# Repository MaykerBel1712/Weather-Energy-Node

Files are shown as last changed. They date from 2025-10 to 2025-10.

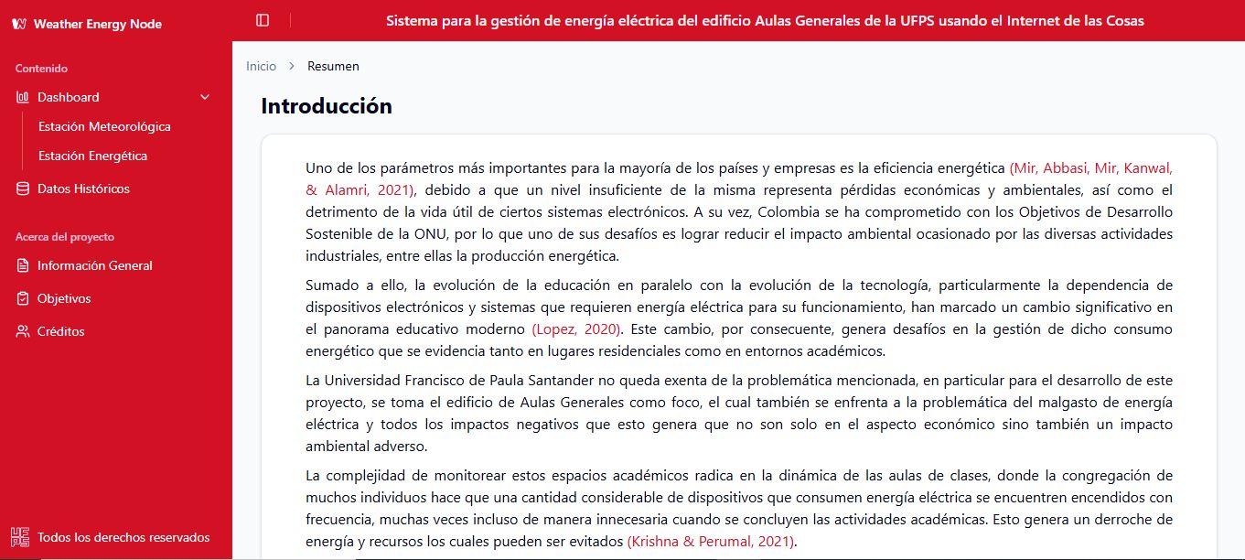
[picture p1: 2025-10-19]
docs/Página/INFO.JPG

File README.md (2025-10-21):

# Proyecto de Tesis — Sistema Integrado de Monitoreo Ambiental, Energético y Domótica UFPS

## 📘 Descripción general

Este proyecto corresponde al desarrollo de una **plataforma integral de monitoreo y control** para el edificio de Aulas Generales de la **Universidad Francisco de Paula Santander (UFPS)**.
Combina módulos de **estación meteorológica**, **monitoreo energético** y **domótica**, integrados a una **plataforma web interactiva** con visualización de datos en tiempo real.

---

## Componentes del sistema

### 1. Estación Meteorológica

* Microcontrolador: **ESP32**
* Sensores: temperatura, humedad, radiación solar, velocidad del viento, material particulado (PM1.0, PM2.5, PM4.0, PM10) e índice VOC.
* Funcionalidad: recolección y envío de datos a **Firebase Realtime Database**.
* Mecanismo de respaldo: almacenamiento temporal en memoria interna cuando no hay conexión a internet.

### 2. Módulo de Monitoreo Energético

* Microcontrolador: **ESP32**
* Sensor: medidor Eastron SDM630MTC (RS485)
* Funcionalidad: medición de variables eléctricas del edificio, envío a Firebase y almacenamiento local en caso de pérdida de conexión.

### 3. Módulos de Domótica

* Módulo **transmisor**: detecta presencia y envía señal.
* Módulo **receptor**: acciona dispositivos eléctricos del salón.
* Tecnología: comunicación inalámbrica entre módulos basados en ESP32.

### 4. Plataforma Web

* Framework: **Next.js**
* Estilo: **Tailwind CSS + shadcn/ui**
* Funcionalidades:

  * Visualización de datos meteorológicos y energéticos en tiempo real.
  * Gráficas interactivas con **Plotly.js**.
  * Panel principal de control (Dashboard).
  * Integración con Firebase Hosting y Database.

---

## Estructura del Repositorio

Cada subcarpeta incluye su propio `README.md` explicando su función y configuración.

```
.gerber/           → Archivos de los circuitos impresos
firmware/          → Códigos de los ESP32
web_app/           → Página web del sistema
docs/              → Documentación técnica, diagramas e imágenes del proceso de desarrollo
```

---

##  Infraestructura general

El sistema opera bajo el siguiente flujo:

1. **Captura de datos** desde sensores (ambientales y eléctricos).
2. **Transmisión** mediante ESP32 hacia Firebase Realtime Database.
3. **Visualización y control** a través de la página web alojada en Firebase Hosting.
4. **Respaldo local** en memoria interna del ESP32 cuando no hay conexión.

---

## Tecnologías principales

* **ESP32** (Programado en PlatformIO / Arduino)
* **Firebase Realtime Database & Hosting**
* **Next.js + Tailwind CSS + shadcn**
* **C++ / JavaScript / HTML / CSS**

---

##  Autores

* Mayker Beltrán
  *Ingeniería Electrónica — Universidad Francisco de Paula Santander (UFPS)*
* Jesús López
  *Ingeniería Electrónica — Universidad Francisco de Paula Santander (UFPS)*
* Sergio Sepúlveda
  *Ingeniería Electrónica — Universidad Francisco de Paula Santander (UFPS)*
* Mario Illera
  *Ingeniería Electrónica — Universidad Francisco de Paula Santander (UFPS)*

---

##  Licencia

Este proyecto se distribuye bajo la licencia **MIT**, permitiendo su uso académico y de investigación.

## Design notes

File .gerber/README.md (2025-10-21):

# Archivos Gerber de las PCB

Este directorio contiene los archivos **Gerber** generados para la fabricación de las diferentes placas de circuito impreso (PCB) del proyecto en la plataforma EasyEDA. Cada carpeta corresponde a un módulo o sistema específico dentro del diseño general.

## 📁 Estructura de carpetas

- **Gerber_ModuloDeteccion_PCB_ModuloDeteccion**  
  Contiene los archivos Gerber del módulo encargado de la detección de eventos o señales en el sistema.

- **Gerber_ModuloSSR_PCB_ModuloSSR**  
  Incluye los archivos Gerber del módulo de control mediante relés de estado sólido (SSR).

- **Gerber_PCB_1_Energia_PCB_PCB_1_Energia**  
  Archivos Gerber correspondientes al módulo de gestión y monitoreo de energía eléctrica.

- **Gerber_PCB_2_Weather_PCB_PCB_2_Weather**  
  Archivos Gerber del módulo meteorológico para la medición de variables ambientales (temperatura, humedad, presión, etc.).

## 📜 Descripción general

Los archivos Gerber son los utilizados por los fabricantes de PCB para producir las placas físicas.  
Cada carpeta contiene los siguientes tipos de archivos típicos:

- `.gbr` o `.ger` → Capas de cobre, máscara, serigrafía, etc.  
- `.drl` → Archivo de perforación (taladros).  
- `.txt` o `.gbl/.gtl/.gts` → Capas inferiores/superiores y detalles de fabricación.

## ⚙️ Recomendaciones para fabricación

- Verificar las dimensiones y el grosor del PCB antes de enviar a fabricación.  
- Asegurarse de incluir los archivos de taladros (`.drl`) y la vista previa del ensamblaje si el fabricante lo solicita.  
- Se recomienda usar un fabricante como **JLCPCB**, **PCBWay** o similar.  
- Todos los diseños han sido generados y revisados con **KiCad** (o el software de diseño utilizado en el proyecto).

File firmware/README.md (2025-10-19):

Contiene todo el código que se ejecuta en los microcontroladores (principalmente ESP32) del proyecto: estación meteorológica, monitoreo de energía y módulos de domótica. Este README.md documenta la estructura, dependencias, configuración, compilación, despliegue, buenas prácticas y resolución de problemas para los subproyectos de firmware.

📁 Estructura recomendada
```
firmware/
├── estacion_meteorologica/
│   ├── src/
│   │   ├── main.cpp
│   │   ├── sensores.cpp
│   │   └── firebase.cpp
│   ├── include/
│   ├── lib/
│   ├── test/
│   ├── platformio.ini
│   └── README.md
│
├── monitoreo_energia/
│   ├── src/
│   │   ├── main.cpp
│   │   ├── eastron.cpp
│   │   └── firebase.cpp
│   ├── include/
│   ├── lib/
│   ├── platformio.ini
│   └── README.md
│
└── domotica/
    ├── modulo_receptor/
    ├── modulo_transmisor/
    └── README.md
```

## 🧭 Resumen de responsabilidades por subproyecto

- **`estacion_meteorologica/`**  
  Lectura y procesamiento de sensores ambientales (ej. SEN54), muestreo, filtrado y envío de datos a Firebase.  
  Almacenamiento temporal en LittleFS cuando no hay conectividad.

- **`monitoreo_energia/`**  
  Comunicación RS485/Modbus con medidor Eastron SDM630MTC; lectura de magnitudes eléctricas, cálculo/registro y envío a Firebase.

- **`domotica/`**  
  Comunicación entre módulos transmisor/receptor, gestión de actuadores (relés, PWM), reglas locales y comunicación con la red.

---

## 🛠 Requisitos (software & hardware)

### 💻 Software recomendado

- Visual Studio Code + extensión PlatformIO IDE  
- PlatformIO Core (`pio`) para CLI (opcional)  
- Git  
- (Opcional) `esptool.py` para flasheos manuales

### 📚 Librerías sugeridas (`lib_deps`)

- `mobizt/Firebase Arduino Client Library for ESP8266 and ESP32`  
- `lorol/LittleFS_esp32` o `SPIFFS`  
- `ArduinoJson`  
- `Adafruit Unified Sensor` (si aplica)  
- `sensirion/Sensirion I2C SEN5X` (SEN54)  
- `ModbusMaster` (o equivalente) para RS485/Modbus  
- `AsyncTCP` / `ESPAsyncWebServer` (si se ofrece interfaz web/OTA)

### 🔌 Hardware típico

- ESP32 (modelo según disponibilidad y uso)  
- Sensor SEN54 (VOC, PM, humedad, temperatura)  
- Eastron SDM630MTC (salida RS485)  
- Conversor RS485 ↔ TTL / USB-RS485  
- Componentes de alimentación y protección (reguladores, divisores, optoaisladores si aplica)

## 🔐 Manejo de credenciales y seguridad

- **No subir credenciales, claves o `serviceAccount` al repositorio público.**
- Mantener un archivo de ejemplo (`config_example.h` o `config_example.json`) con *placeholders* y documentar el formato.
- Añadir a `.gitignore` los archivos que contengan credenciales:

  ```gitignore
  /firmware/*/src/secrets.h
  /firmware/*/src/config_local.json
- Documentar en cada subproyecto dónde colocar las credenciales (p. ej. src/secrets.h) y cómo formatearlas.

## 🧩 Archivos y módulos clave (qué hacen)

- `src/main.cpp` — Inicialización del hardware, conectividad y loop/RTOS principal.
- `src/sensores.*` — Lectura, calibración y filtrado de sensores ambientales.
- `src/eastron.*` — Implementación de lectura Modbus/RS485 y parsing de registros.
- `src/firebase.*` — Funciones de conexión, reintentos y escritura/lectura en Firebase.
- `include/` — Cabeceras y definiciones compartidas (pinout, estructuras).
- `lib/` — Librerías locales empaquetadas.
- `test/` — Pruebas unitarias (PlatformIO + Unity).
- `platformio.ini` — Configuración del entorno y dependencias.

---

## 📦 Compilar y subir

### En Visual Studio Code (PlatformIO UI)

1. Abrir la carpeta del subproyecto (`firmware/estacion_meteorologica`)
2. Ir a PlatformIO → **Build (✓)** para compilar
3. Conectar el ESP32 por USB → **Upload (→)** para subir
4. Abrir **Monitor** para ver la salida serial

### 🖥️ En terminal (PlatformIO CLI)

```bash
cd firmware/estacion_meteorologica
pio run              # compilar
pio run -t upload    # compilar y subir
pio device monitor   # abrir monitor serial
# o con velocidad específica:
pio device monitor -b 115200
```

## 🔁 Almacenamiento local y sincronización

- Usar **LittleFS** para persistir mediciones cuando no hay red.
- Política recomendada: límite de almacenamiento (N registros o X MB) y orden por timestamp.
- Al restablecer la conexión: reenviar registros pendientes en orden cronológico y marcarlos/borrarlos tras confirmación.

---

## 🔌 Comunicación RS485 (Eastron SDM630MTC)

- Usar librería **Modbus** (por ejemplo `ModbusMaster`)
- Controlar pin **DE/RE** del transceiver: nivel alto para transmitir, bajo para recibir
- Configurar **baudrate**, **parity** y **timeouts** de acuerdo al manual del medidor
- Validar **CRC** y manejar reintentos/timeouts; introducir **delays** entre peticiones si el bus lo requiere

---

## 🔄 Actualizaciones OTA (opcional)

- Integrar `ArduinoOTA` o un servidor de actualización seguro (HTTPS + autenticación)

### Consideraciones

- Particiones (espacio para OTA)
- Seguridad: firma/validación del binario
- Mecanismo de rollback si la actualización falla

---

## 🧪 Tests y CI

### 🧪 Tests

- Usar **PlatformIO + Unity** para unit tests en `test/`
- Priorizar pruebas para:
  - Parsing Modbus
  - Serialización/deserialización JSON
  - Lógica de reintentos y compactación de registros

### ⚙️ CI (recomendado)

- Crear workflow en `.github/workflows/ci.yml` que ejecute `pio run` en cada subproyecto para validar compilación en PRs
- Añadir checks opcionales: `clang-format`, `linting` y ejecución de tests

---

## 🐞 Troubleshooting (problemas comunes)

- **Errores de dependencias**: borrar `.pio/libdeps` y recompilar; fijar versiones en `lib_deps`
- **TLS/HTTPS falla al conectar a Firebase**: verificar fecha/hora del dispositivo (NTP)
- **Lecturas Modbus erráticas**: revisar DE/RE, GND común, niveles lógicos, CRC, delays entre peticiones y baudrate
- **Particiones insuficientes**: ajustar `board_build.partitions` en `platformio.ini`
- **Upload falla**: revisar drivers USB, permisos y puerto COM; probar con `esptool` si es necesario

---

## ✅ Checklist antes de un Pull Request (PR)

- [ ] El subproyecto compila localmente (`pio run`)
- [ ] No se incluyen credenciales en el commit
- [ ] `platformio.ini` actualizado si se añadieron dependencias
- [ ] README del subproyecto actualizado y coherente
- [ ] Tests añadidos/actualizados cuando aplique
- [ ] Diagramas de conexión actualizados en `docs/diagramas/` cuando cambie hardware

---

## 🧾 Buenas prácticas de desarrollo

- Separar responsabilidades: adquisición, comunicación, almacenamiento y lógica
- Documentar APIs públicas en `.h` (descripción, parámetros, retornos)
- Implementar políticas de reintentos con **backoff exponencial** para operaciones de red
- Registrar logs con niveles (`DEBUG`, `INFO`, `WARN`, `ERROR`) y posibilidad de reducir verbosidad en producción
- Mantener formato y estilo de código consistentes (usar `clang-format` o similar)

---

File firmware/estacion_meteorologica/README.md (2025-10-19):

# Estación Meteorológica — weatherEnergyNode

**Carpeta:** `firmware/estacion_meteorologica/`  
**Propósito:** Firmware para el nodo de estación meteorológica basado en ESP32. Lee sensores ambientales cuyas variables sos material particulado, velocidad de viento, temperatura, humedad, radiación solar. Procesa y valida lecturas, almacena temporalmente en LittleFS cuando no hay conexión y sincroniza los datos a Firebase (Realtime Database).

---

## Contenido de la carpeta
```plaintext
.
├── .pio/                  # Archivos generados por PlatformIO (compilación, dependencias)
├── .vscode/              # Configuración de VS Code (opcional)
├── include/              # Cabeceras compartidas (.h)
├── lib/                  # Librerías locales empaquetadas
├── src/                  # Código fuente principal (.cpp)
├── test/                 # Pruebas unitarias (PlatformIO + Unity)
├── .gitignore            # Exclusión de archivos sensibles y temporales
└── platformio.ini        # Configuración del entorno PlatformIO
```

---

## Resumen funcional
- Inicializa y mantiene la conexión Wi-Fi.
- Lee sensores ambientales periódicamente: temperatura, humedad, VOC, PM, radiación solar, velovidad del viento.
- Guarda registros en **LittleFS** si la conexión a Firebase falla.
- Reintenta y sincroniza registros pendientes cuando la conexión se restablece.

---

## Hardware soportado (ejemplos)
- **Microcontrolador:** ESP32.
- **Sensores (ejemplos):**
  - SEN54
  - Apogee SP110
  - QS-FS201
  - 

- Conversor análogo digital ADC1115
- Conexiones recomendadas:
  - I²C: SDA → pin I2C SDA del ESP32, SCL → pin I2C SCL. Usar resistencias pull-up si el módulo no las incluye.
  - Alimentación: respetar corriente y vooltajes de los sensores.
  - GND común.

> **Nota:** Verifica el datasheet de tu sensor para valores exactos de conexión y consumo.

---

## Requisitos de software
- Visual Studio Code + PlatformIO IDE (recomendado).
- PlatformIO Core (CLI) opcional: `pio`.
- Librerías (añadir en `lib_deps` en `platformio.ini`):
  - `mobizt/Firebase Arduino Client` (si usas Firebase).
  - `lorol/LittleFS_esp32` o `SPIFFS`.
  - `bblanchon/ArduinoJson`.
  - Librería del sensor (p. ej. `sensirion/Sensirion I2C SEN5X`).
  - `Adafruit Unified Sensor` (si aplica).

---

## Archivo de ejemplo: `platformio.ini`
```ini
[env:esp32dev]
platform = espressif32
board = esp32dev
framework = arduino
monitor_speed = 115200

lib_deps =
  mobizt/Firebase Arduino Client@^4.4.14
  lorol/LittleFS_esp32@^1.0.6
  bblanchon/ArduinoJson@^6.18.5
  sensirion/Sensirion I2C SEN5X@^1.0.0

; Ajustar particiones si requiere LittleFS o OTA
; board_build.partitions = default
```
## 🔐 Manejo de credenciales (importante)

- **NO versionar archivos con credenciales reales.**
- Añadir a `.gitignore` los archivos que contengan datos sensibles, por ejemplo:

  ```gitignore
  src/secrets.h
  config_local.json
  ```
  ## 📤 Formato de datos enviado a Firebase (ejemplo)

Se recomienda enviar un **objeto JSON por medición**, incluyendo una marca de tiempo en formato **ISO 8601** (`YYYY-MM-DD HH:mm:ss`) o **epoch**. Esto facilita la trazabilidad, orden cronológico y compatibilidad con bases de datos.

### 🧾 Ejemplo de payload

```json
{
  "AmbientHumidity": "47.35",
  "AmbientTemperature": "33.97",
  "Irradiance": 0,
  "MassConcentrationPm10p0": 1.8,
  "MassConcentrationPm1p0": 1.7,
  "MassConcentrationPm2p5": 1.8,
  "MassConcentrationPm4p0": 1.8,
  "SolarRadiationVoltage": 0,
  "VocIndex": "59.00",
  "WindSpeed": 0.080051,
  "timestamp": "2025-10-19 12:32:09"
}
```
## 💾 Almacenamiento local (LittleFS)

- Guardar registros en formato **JSON**, ya sea línea por línea o como archivos de logs rotativos.
- Política sugerida:
  - Máximo **N registros** o **M MB**.
  - Envío de registros desde el más antiguo al más reciente al reconectar.
  - Confirmación de entrega antes de borrar localmente.
  - Implementar compactación periódica si el espacio es limitado.

---

## 🔄 Flujo de operación (resumen)

1. **Arranque**  
   Inicializar hardware, buses I²C, sistema de archivos (FS) y conexión Wi-Fi.

2. **Sincronización**  
   Si hay conexión Wi-Fi → sincronizar registros pendientes almacenados localmente.

3. **Ciclo de muestreo**  
   Leer sensores → aplicar filtrado → validar datos → almacenar y/o emitir.

4. **Envío a Firebase**  
   Si el envío falla → guardar localmente y reintentar con política de *backoff* exponencial.

5. **Opcional**  
   Exponer un endpoint local para configuración o diagnóstico.

---

## 🧪 Compilar y flashear

### Desde PlatformIO (Visual Studio Code)

1. Abrir la carpeta `firmware/estacion_meteorologica` en VS Code.
2. Ir a PlatformIO → **Build (✓)** para compilar.
3. Conectar el ESP32 por USB → **Upload (→)** para subir el firmware.
4. Abrir **Monitor** para revisar los logs en tiempo real.

## 🧪 Tests y CI recomendados

### 🧪 Tests unitarios con PlatformIO + Unity (`test/`)

- Parser de mensajes del sensor
- Serialización JSON
- Lógica de reintentos y almacenamiento

### ⚙️ CI con GitHub Actions

- Crear un workflow que ejecute `pio run` en cada Pull Request (PR)
- Opcional:
  - Checks de estilo con `clang-format`
  - Ejecución automática de tests unitarios

---

## 🐞 Troubleshooting (problemas habituales)

### 🔌 Sensor no responde (I²C)

- Verificar conexiones **SDA/SCL** y **GND común**
- Comprobar resistencias **pull-up**
- Usar **scanner I²C** para confirmar dirección del dispositivo

### 📉 Lecturas erráticas o fuera de rango

- Aplicar filtros (ej. **mediana**)
- Comprobar calibración de sensores

### 🔐 Conexión a Firebase falla (TLS)

- Verificar **reloj del dispositivo (NTP)** — una fecha incorrecta rompe TLS
- Confirmar valores de `FIREBASE_HOST` y credenciales

### 💾 LittleFS lleno

- Implementar **rotación de archivos** y límites de almacenamiento
- Registrar y revisar logs de uso del sistema de archivos

### 🚫 Upload/Flasheo falla

- Revisar **drivers USB**, puerto correcto y permisos (Linux/Mac)
- Probar con `esptool` si persiste el problema

---

## 🧾 Buenas prácticas

- Mantener **separación de capas**: sensores, comunicación, almacenamiento
- Usar **retries con backoff exponencial** para operaciones de red
- Manejar errores de forma explícita y registrar con niveles (`DEBUG`, `INFO`, `WARN`, `ERROR`)
- No bloquear el **loop principal**; usar timers o tareas FreeRTOS para muestreo y envío
- Documentar pines y conexiones en `docs/`

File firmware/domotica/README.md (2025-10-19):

# Domótica — weatherEnergyNode

**Carpeta:** `firmware/domotica/`  
**Propósito:** Firmware para el subsistema de domótica del proyecto. Está compuesto por **dos módulos**:

- `modulo_transmisor/` — detector de presencia (PIR + radar).  
- `modulo_receptor/` — actuador que conmuta cargas mediante **3 SSR de 25 A** instalados en el tablero del salón.

**Comunicación entre módulos:** Bluetooth Low Energy (BLE).  

---

## 📁 Estructura

```plaintext
.
├── .pio/                  # Archivos generados por PlatformIO (compilación, dependencias)
├── .vscode/              # Configuración de VS Code (opcional)
├── include/              # Cabeceras compartidas (.h)
├── lib/                  # Librerías locales empaquetadas
├── src/                  # Código fuente principal (.cpp)
├── test/                 # Pruebas unitarias (PlatformIO + Unity)
├── .gitignore            # Exclusión de archivos sensibles y temporales
└── platformio.ini        # Configuración del entorno PlatformIO
```
---

## Resumen funcional
- **Transmisor (detector)**:
  - Lee señales de **PIR** y **sensor radar**.
  - Realiza filtrado y lógica de fusión ( PIR+radar para mayor certeza).
  - Envía evento(s) y estado por **BLE** al receptor.
  - Indicadores LED y botón de test/calibración.

- **Receptor (actuador)**:
  - Mantiene enlace BLE con el transmisor.
  - Recibe comandos / eventos y acciona los **3 SSR (25 A)** para conmutar cargas del salón.
  - Implementa seguridad básica: validación origen, ACKs y límites.
  - Proporciona modo manual (botón local) y estado de salida.

---

## Hardware y conexiones (puntos claves)

### Sensores (transmisor)
- **PIR**: detecta cambios de radiación térmica.
- **Radar**: detecta movimiento incluso detrás de obstáculos y con mejor sensibilidad para movimientos lentos.
- Uso combinado:
  - PIR confirma presencia humana por calor.
  - Radar detecta movimiento hasta en condiciones donde PIR falla (por ejemplo: movimiento lento o detrás de vidrio).
  - Lógica típica: `presence = (PIR && radar_recent) || (radar_strong && debounce)` para reducir falsos positivos.

### Actuadores (receptor)
- **3 x SSR (25 A)** instalados en el tablero para conmutar las cargas del salón (iluminación, ventilación, otro circuito).
- **Nota importante sobre SSRs**:
  - Elegir SSRs adecuados al tipo de carga (resistiva vs inductiva). Para cargas inductivas/motores conviene SSRs con especificaciones y/o usar contactores mecánicos.
  - SSR tipo **zero-cross**: recomendado para cargas resistivas (iluminación LED simple) — no sirve para control por fase (no dimming por ángulo de fase).
  - SSRs **disipan calor**: dimensionar disipadores y/o ventilación. Revisar la pérdida de tensión del SSR (typ. 1–2 V) y calcular disipación `P = V_drop * I`.
  - Asegurar que la SSR acepta **entrada de control a 3.3 V** (muchos aceptan 3–32 V). Si no, usar un driver (transistor/MOSFET o optoacoplador).
  - Proveer **fusibles/interruptores** y protección por canal en el tablero (cada SSR + carga con su protección).

### Alimentaciones y puesta a tierra
- **Cada SSR y cada carga** debe disponer de su alimentación y protección adecuada. Si las cargas son de red (mains), usar conductores con sección adecuada a la corriente esperada y protecciones diferenciales/termomagnéticas conforme a normativa local.
- **Conductor recomendado (orientativo):** para corrientes hasta 25 A se suele usar cableificación ≥ 2.5 mm²; por seguridad y según normativa local preferir 4 mm² para 25 A continuos especialmente si hay temperatura ambiente alta o conductores agrupados. Verifica normas eléctricas locales.
- **GND común de control:** Si el SSR requiere referencia común para la señal de control y el ESP32 comparte alimentación con el driver, conectar GND de control; si SSR entrada es aislada ópticamente, seguir las recomendaciones del fabricante.
- **Seguridad:** aislamiento galvánico, bornes bien aislados, canalización adecuada y señalización.

---

## Seguridad eléctrica (imprescindible)
- Trabajos en 110/220 V CA deben ser realizados por personal calificado.
- Instalar **fusibles/interruptores automáticos** por canal (dimensionados al consumo de la carga).
- Poner **protección diferencial (RCD)** en el tablero si hay exposiciones en salones.
- Usar **bornes y canalización** apropiada, y protección mecánica para los SSR.
- Añadir **MOVs / supresores** si hay riesgo de sobretensiones en cargas inductivas.
- Documentar esquemas y etiquetar cada canal en el tablero.

---

## BLE — diseño de comunicación (GATT + recomendaciones)

### Roles
- **Transmisor (detector)** → **Periférico (advertising)** o periférico con servicio GATT.  
- **Receptor (actuador)** → **Central** que se conecta al periférico y suscribe/lee características.

### Recomendación operativa
- Usar **advertising** para eventos puntuales (muy bajo consumo y sin conexión) o GATT con notificaciones si se necesita ACK y control bidireccional.
- Para confiabilidad y ACKs usar **GATT + Notificaciones** (conexión establecida entre módulos).

## 🔐 Seguridad BLE

- Usar **emparejamiento y bonding** si es necesario, para evitar conexiones indeseadas o no autorizadas.
- Minimizar la exposición de **characteristics de escritura** sin autenticación.
- Considerar el uso de **encriptación BLE Secure Connections** si existe riesgo físico de manipulación del dispositivo.

> Se recomienda revisar las políticas de seguridad del stack BLE utilizado (ej. NimBLE, Bluedroid) y validar que los permisos de acceso estén correctamente configurados para cada characteristic.

## 🧠 Lógica sugerida de detección (PIR + radar)

### 🔧 Variables

- `pir_raw` (boolean)
- `radar_raw` (boolean)
- `last_pir_time`
- `last_radar_time`

---

### 📋 Algoritmo básico

1. **Leer sensores**
2. **Aplicar debounce**  
   Ignorar cambios menores a `T_debounce` (ej. `200–500 ms`)
3. **Confirmación de presencia**
   - Si `pir_raw == true` **y** `radar_raw == true` → **presencia confirmada** (alta confianza)
   - Si solo `radar_raw == true` → marcar como `possible_presence`, esperar ventana `T_confirm` (ej. `2–5 s`) para confirmar
   - Si solo `pir_raw == true` → confirmar si `radar_raw` reporta movimiento en ventana corta (reduce falsos positivos por calor ambiental)
4. **Acción tras detección**
   - Si presencia confirmada:
     - Enviar evento BLE
     - Activar salida local (ej. LED)
     - Si receptor responde `ACK` → accionar SSRs según políticas
5. **Auto-off por inactividad**
   - Apagar salidas después de `N` minutos sin eventos

---

> Esta lógica combina detección térmica (PIR) y microondas (radar) para mejorar la confiabilidad en entornos con ruido térmico o movimiento leve. Se recomienda ajustar `T_debounce` y `T_confirm` según el entorno físico y el tipo de aplicación.

## ✅ Pruebas y validación

### 🧪 Tests unitarios (PlatformIO + Unity)

- Parser de payload BLE
- Lógica de debounce y fusión PIR + radar
- Simulación de reintentos y recepción de ACK

### 🔧 Tests hardware

- Validar que los SSRs cortan correctamente y soportan la carga medida sin sobrecalentamiento
- Medir corriente de entrada al SSR LED para verificar si la salida GPIO es suficiente

### 🧪 Pruebas de campo

- Colocar el sistema en condiciones reales del salón para ajustar sensibilidad y temporizadores
- Verificar alcance BLE y efectos de obstáculos físicos

---

## 🐞 Troubleshooting (problemas frecuentes)

### 📡 No hay conexión BLE

- Verificar que ambos módulos usen el mismo canal y stack compatible (NimBLE vs Bluedroid)
- Comprobar emparejamiento y bonding

### 🚨 Falsos positivos en detección

- Ajustar sensibilidad del PIR
- Refinar lógica de confirmación combinada con radar
- Agregar ventana temporal de confirmación y filtrado por duración de evento

### 🔥 SSRs se calientan

- Verificar caída de tensión (`V_drop`) y corriente real
- Añadir disipador térmico y/o ventilación
- Confirmar que el SSR sea adecuado para el tipo de carga (motor, luminaria, etc.)

### ⚡ Relés no conmutan con GPIO 3.3 V

- Medir corriente y tensión en la entrada del SSR
- Si es insuficiente, añadir driver (transistor u optoacoplador)

### 📶 Interferencias en radar por señales eléctricas

- Separar cables de señal de los conductores de potencia
- Usar apantallamiento si es necesario

---

## 📋 Checklist antes de PR / despliegue

- [ ] Compila localmente ambos módulos (`pio run`)
- [ ] Las señales de control del SSR han sido verificadas con osciloscopio o multímetro
- [ ] Cada SSR cuenta con protección (fusible o breaker) en el tablero
- [ ] Documentación de conexión subida a `docs/diagramas/`
- [ ] Tests unitarios básicos implementados
- [ ] Procedimiento de seguridad eléctrica documentado y revisado por técnico

---

## 📚 Recursos y referencias

- Datasheets de sensores PIR y radar (colocar enlaces en `docs/diagramas/`)
- Datasheet del SSR elegido (entrada de control, caída de tensión, corriente máxima, disipación)
- Documentación oficial de [NimBLE-Arduino](https://github.com/h2zero/NimBLE-Arduino) y ejemplos BLE GATT
- Normativa eléctrica local para dimensiones de conductor y protecciones

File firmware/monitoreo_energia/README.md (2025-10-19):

# Monitoreo de Energía — weatherEnergyNode

**Carpeta:** `firmware/monitoreo_energia/`  
**Propósito:** Firmware para el nodo de monitoreo energético basado en ESP32. Lee un medidor eléctrico (Eastron SDM630MTC) mediante RS485/Modbus, procesa lecturas (voltaje, corriente, potencia, energía entre otras), almacena temporalmente en LittleFS y sincroniza con Firebase (Realtime Database).

---
## 📁 Contenido 
```plaintext
.
├── .pio/                 # Archivos generados por PlatformIO (compilación, dependencias)
├── .vscode/              # Configuración de VS Code (opcional)
├── include/              # Cabeceras compartidas (.h)
├── lib/                  # Librerías locales empaquetadas
├── src/                  # Código fuente principal (.cpp)
├── test/                 # Pruebas unitarias (PlatformIO + Unity)
├── .gitignore            # Exclusión de archivos sensibles y temporales
└── platformio.ini        # Configuración del entorno PlatformIO
```

---

## 🔎 Resumen funcional
- Comunica con el medidor Eastron SDM630MTC (u otro compatible Modbus RTU) vía RS485.
- Solicita registros periódicamente (tensión, corriente, potencia instantánea, energía acumulada, factor de potencia, etc.).
- Guarda lecturas en LittleFS si falla la conexión a la nube.
- Envía datos a Firebase, con reintentos y política de backoff.
- Opcional: expone endpoint local para diagnóstico y configuración.

---

## 🛠 Requisitos (software & librerías)

### Software recomendado
- Visual Studio Code + PlatformIO IDE.
- PlatformIO Core (`pio`) opcional.
- Git.

### Librerías sugeridas (`lib_deps`)
- `paulstoffregen/ModbusMaster` (o `ArduinoModbus` / `SimpleModbusMaster` según preferencia)
- `mobizt/Firebase Arduino Client` (si se usa Firebase)
- `lorol/LittleFS_esp32` o `SPIFFS`
- `bblanchon/ArduinoJson`
- `AsyncTCP` / `ESPAsyncWebServer` (opcional, para interfaz/OTA)

> Fija versiones en `platformio.ini` para evitar rupturas futuras.

---

## 🔌 Hardware y conexiones RS485
- **Medidor:** Eastron SDM630MTC (RS485).
- **Transceiver RS485:** módulo MAX485, ADM485 u otro compatible.
- **Conexiones básicas:**
  - A (A) ↔ A del transceiver
  - B (B) ↔ B del transceiver
  - GND común entre ESP32 y transceiver
  - DE/RE del transceiver controlado por GPIO del ESP32 (por ejemplo `GPIO_NUM`) — alto = transmisión, bajo = recepción
- **Alimentación:** respetar tensiones y aislar si es necesario.

---

## ⚙️ Ejemplo de `platformio.ini`
```ini
[env:esp32dev]
platform = espressif32
board = esp32dev
framework = arduino
monitor_speed = 115200

lib_deps =
  paulstoffregen/ModbusMaster@^2.0.4
  mobizt/Firebase Arduino Client@^4.4.14
  lorol/LittleFS_esp32@^1.0.6
  bblanchon/ArduinoJson@^6.18.5

; Ajusta board y particiones según necesidad
```
## 📐 Configuración Modbus — parámetros típicos

Estos parámetros deben ajustarse según el modelo del medidor ( **Eastron SDM630MTC**) y las condiciones del bus RS485.

- **ID del dispositivo (slave)**: `1` (configurable según el medidor)
- **Baudrate**: `9600` (o `2400` / `19200` según el dispositivo)
- **Paridad**: `Even` / `None` (según el medidor)
- **Stop bits**: `1`
- **Timeouts**:
  - Configurar timeout de lectura apropiado (ej. `200–500 ms`)
  - Implementar reintentos en caso de fallo
- **Registros a leer**:
  - Usar direcciones según el manual del Eastron
  - Ejemplos comunes:
    - Tensiones por fase
    - Corrientes
    - Potencia activa
    - Energía total acumulada

> Se recomienda validar el CRC de cada respuesta y aplicar **delays entre peticiones** si el bus lo requiere para evitar colisiones o lecturas incompletas.

## 🧾 Formato de datos enviado a Firebase (ejemplo)

Se recomienda estructurar los datos por `timestamp`, enviando cada medición como un objeto JSON que contenga los registros relevantes del dispositivo.

### 📦 Estructura sugerida

```json
{
  "deviceId": "medidor_01",
  "timestamp": "2025-10-19T12:30:00",
  "data": {
    "V1": "0x0000",
    "V2": "0x0002",
    "V3": "0x0004",

    "I1": "0x0006",
    "I2": "0x0008",
    "I3": "0x000A",
    "IN": "0x00E0",

    "PA1": "0x000C",
    "PA2": "0x000E",
    "PA3": "0x0010",
    "PAT": "0x0034",

    "VA1": "0x0012",
    "VA2": "0x0014",
    "VA3": "0x0016",
    "VAT": "0x0038",

    "PR1": "0x0018",
    "PR2": "0x001A",
    "PR3": "0x001C",
    "PRT": "0x003C",

    "FP1": "0x001E",
    "FP2": "0x0020",
    "FP3": "0x0022",
    "FPT": "0x003E",

    "Prom_volts_L_N": "0x002A",
    "Prom_I_L": "0x002E",
    "Suma_I_L": "0x0030",

    "F": "0x0046",

    "ETI": "0x0048",
    "ETE": "0x004A",
    "kVArhTI": "0x004C",
    "kVArhTE": "0x004E",

    "T_KVAh": "0x0050",
    "T_Ah": "0x0052",

    "Demanda_PTS_W": "0x0054",
    "Demanda_Max_PTS_VA": "0x0056",
    "Demanda_TS_VA": "0x0064",

    "V_1_2": "0x00C8",
    "V_2_3": "0x00CA",
    "V_3_1": "0x00CC",
    "V_prom_L_L": "0x00CE",

    "VTHD_LN_1": "0x00EA",
    "VTHD_LN_2": "0x00EC",
    "VTHD_LN_3": "0x00EE",
    "Prom_VTHD_LN": "0x00F8",

    "ITHD_1": "0x00F0",
    "ITHD_2": "0x00F2",
    "ITHD_3": "0x00F4",
    "ITHD_Prom": "0x00FA",

    "Demanda_I1": "0x0102",
    "Demanda_I2": "0x0104",
    "Demanda_I3": "0x0106",
    "Demanda_Max_I1": "0x0108",
    "Demanda_Max_I2": "0x010A",
    "Demanda_Max_I3": "0x010C",

    "VTHD_1_2": "0x014E",
    "VTHD_2_3": "0x0150",
    "VTHD_3_1": "0x0152",
    "Prom_VTHD_L_L": "0x0154",

    "Tkwh": "0x0156",
    "Tkvarh": "0x0158"
  }
}

```
## 💾 Almacenamiento local (LittleFS)

- Guardar mensajes en formato **JSON**, ya sea como líneas independientes o mediante archivos rotativos.
- **Política recomendada**:
  - Límite en número de registros (ej. `2000`) o tamaño total (ej. `2 MB`)
  - Reintentos periódicos de envío
  - Confirmación de entrega antes de borrar localmente
  - Orden de envío: del **más antiguo al más reciente**

> Se recomienda implementar compactación o rotación si el espacio disponible es limitado, y registrar métricas de uso del sistema de archivos.

---

## 🧪 Compilar y flashear

### Desde Visual Studio Code (PlatformIO UI)

1. Abrir la carpeta `firmware/monitoreo_energia`
2. Ir a PlatformIO → **Build (✓)** para compilar
3. Conectar el ESP32 por USB → **Upload (→)** para flashear
4. Abrir **Monitor serial** para revisar los logs en tiempo real

## 🔁 Estrategia de reintentos y backoff

- Reintento simple con límite (ej. **3 intentos**) para lecturas Modbus
- Para envío a Firebase, usar **backoff exponencial**:
  - Ejemplo: `1s`, `2s`, `4s`, `8s`
  - Máximo: **5 intentos**
- Marcar y persistir errores no recuperables para análisis posterior (logs)

---

## 🔧 Depuración y logs

- Implementar niveles de log: `DEBUG`, `INFO`, `WARN`, `ERROR`
- Logs de Modbus:
  - Mostrar peticiones/respuestas en hexadecimal **solo en nivel DEBUG**
- Contabilizar métricas clave:
  - Número de lecturas
  - Fallos Modbus
  - Fallos de envío
  - Uso y tamaño del sistema de archivos (FS)

---

## ⚠️ Seguridad y protección

- Evitar exponer credenciales por endpoints no autenticados
- Proteger acceso físico a la interfaz RS485 si está en instalaciones públicas
- Para instalaciones críticas:
  - Considerar **aislamiento galvánico** entre el medidor y el ESP32

---

## 🐞 Troubleshooting (problemas comunes)

### 📡 No hay respuesta del medidor

- Revisar **ID del dispositivo** y conexiones **A/B**
- Confirmar **GND común**
- Verificar **Baudrate**, **Parity** y **Stop bits**
- Probar con software o convertidor RS485 externo

### 🔄 Lecturas corruptas / CRC falla

- Verificar cableado, terminación del bus y resistencias de pull-up / terminadores

### 📉 Datos inconsistentes

- Aumentar **timeouts**
- Añadir **reintentos**
- Validar rangos físicos esperados

### 💾 LittleFS lleno

- Implementar **rotación** y limpieza automática
- Aumentar particiones si es necesario

### 🔐 Upload a Firebase falla (TLS)

- Verificar **reloj del dispositivo (NTP)** y credenciales

### 🔁 Problemas de DE/RE (transceiver RS485)

- Asegurar control correcto del pin **DE/RE**
- Respetar tiempos entre toggle y transmisión

---

## ✅ Checklist antes de abrir un Pull Request (PR)

- [ ] Compila correctamente (`pio run`)
- [ ] No se incluyen credenciales en el commit
- [ ] `platformio.ini` actualizado si se agregan librerías
- [ ] Documentación del subproyecto actualizada
- [ ] Tests añadidos/actualizados (si aplica)
- [ ] Diagrama de conexión en `docs/` actualizado si hubo cambios de hardware

---

## 🧾 Tests y CI

### 🧪 Tests unitarios con PlatformIO + Unity

- Parser de respuestas Modbus
- Serialización JSON
- Lógica de reintentos

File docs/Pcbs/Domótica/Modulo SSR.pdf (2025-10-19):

22

55

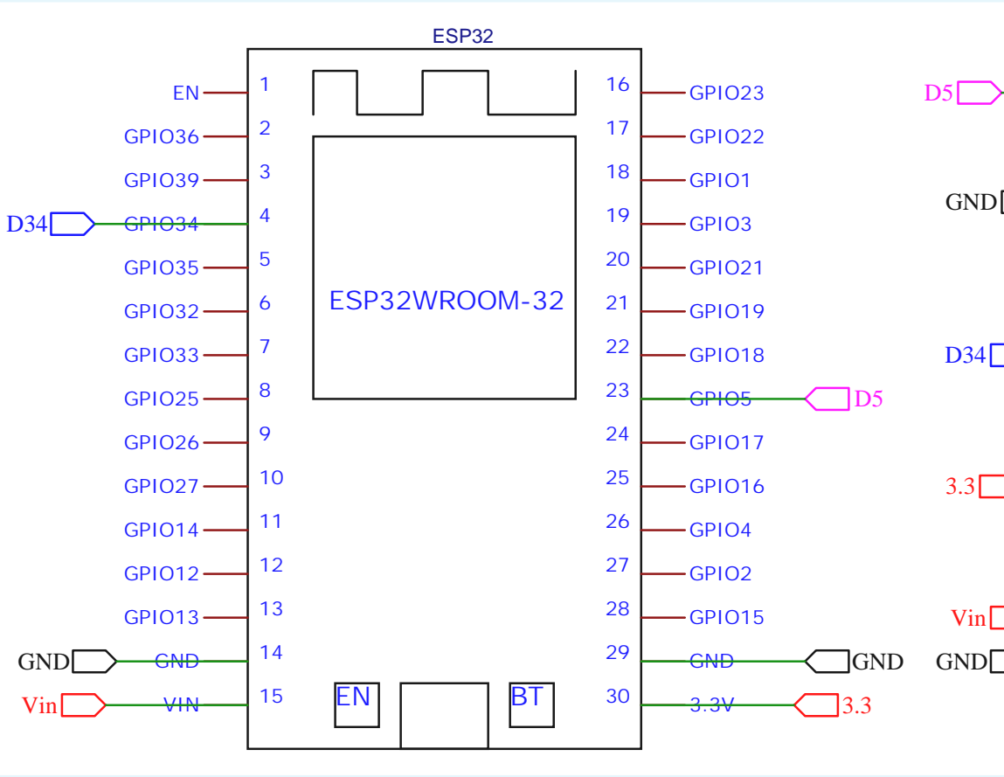
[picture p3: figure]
ESP32; GND 29; GPIO15 28; GPIO2 27; GPIO4 26; GPIO16 25; GPIO17 24; GPIO5 23; GPIO18 22; GPIO19 21; GPIO21 20; GPIO3 19; GPIO1 18; GPIO22 17; VIN; GND; GPIO13; GPIO12; GPIO14; GPIO27; GPIO26; GPIO25; GPIO33; GPIO32; GPIO35; GPIO34; GPIO39; GPIO36; GPIO23 16 EN; ESP32WROOM-32; Vin

SSR

D5G

SWITCH

D43
3.3

ALIMENTACION

VIN G

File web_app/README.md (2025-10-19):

# 🌐 Aplicativo Web — WeatherEnergyNode

Este módulo contiene el [**aplicativo web**](https://prueba-74889.web.app/) del proyecto **WeatherEnergyNode**, un sistema diseñado para la **visualización, análisis y monitoreo en tiempo real** de datos ambientales y energéticos obtenidos desde múltiples nodos basados en **ESP32**.

El aplicativo web fue desarrollado utilizando **Next.js**, **Tailwind CSS**, **shadcn/ui** y se aloja en **Firebase Hosting**, ofreciendo una interfaz moderna, responsiva y modular, optimizada tanto para dispositivos móviles como para escritorio.

---

## 🚀 Características principales

- **Dashboard en tiempo real:** visualización interactiva de variables climáticas y eléctricas mediante gráficos y widgets dinámicos.
- **Conexión directa con Firebase Realtime Database:** los datos de los sensores se actualizan automáticamente.
- **Descarga de datos históricos:** los usuarios pueden exportar datos de los sistemas meteorológicos y de adquisición de energía eléctrica en **CSV o JSON** para análisis posterior.
- **Interfaz modular y profesional:** uso de **shadcn/ui** para componentes como tarjetas, tablas, botones y modales, garantizando un diseño limpio y consistente.
- **Barra lateral y navegación intuitiva:** permite acceder a secciones como Dashboard, Descripción, Autores y otras secciones del proyecto.
- **Colores institucionales:** paleta basada en rojo, gris y blanco, siguiendo la identidad visual de la *Universidad Francisco de Paula Santander*.
- **Hosting seguro y gratuito en Firebase.**

---

## 🗂️ Estructura del proyecto web

Este proyecto utiliza **Next.js**, **Firebase**, y **TypeScript**. A continuación se describe la estructura principal del repositorio:

### 📁 Carpetas

- `.firebase/` — Configuración y caché del CLI de Firebase
- `.next/` — Archivos generados por Next.js durante el build
- `node_modules/` — Dependencias del proyecto instaladas vía npm
- `out/` — Salida del build estático (`next export`)
- `public/` — Archivos estáticos accesibles desde el navegador (imágenes, íconos, etc.)
- `src/` — Código fuente principal (componentes, páginas, lógica de negocio)

---

### 📄 Archivos clave

| Archivo | Descripción |
|---|---|
| `.firebaserc` | Configuración de proyectos Firebase |
| `.firebase.json` | Reglas de hosting, funciones, etc. |
| `.gitignore` | Exclusión de archivos sensibles o generados |
| `.next.config.js` | Configuración personalizada de Next.js |
| `.eslintrc.json` | Reglas de linting para mantener estilo de código |
| `next-env.d.ts` | Tipado automático para Next.js con TypeScript |
| `package.json` | Dependencias, scripts y metadatos del proyecto |
| `package-lock.json` | Versión exacta de dependencias instaladas |
| `postcss.config.js` | Configuración de PostCSS (ej. Tailwind CSS) |
| `tsconfig.json` | Configuración de compilación TypeScript |
---

---

## 🛠️ Tecnologías utilizadas

| Componente | Descripción |
|---|---|
| **Next.js** | Framework de React para el desarrollo del frontend y enrutamiento eficiente. |
| **Tailwind CSS** | Framework CSS para el diseño visual moderno y adaptable. |
| **shadcn/ui** | Librería de componentes UI para interfaces limpias y consistentes. |
| **Firebase Hosting** | Servicio para alojar y publicar el sitio web. |
| **Firebase Realtime DB** | Base de datos en tiempo real usada para mostrar los datos de los sensores. |

---

## 🧠 Estructura visual y componentes

### 🧩 Encabezado

- Nombre de la aplicación
- Título del proyecto
- Logotipo institucional

### 📚 Barra lateral

- Navegación entre secciones:
  - Dashboard
  - Descripción
  - Autores
  - Otros módulos

### 📊 Contenido principal

- Panel con:
  - Gráficos en tiempo real de variables climáticas y energéticas
  - Tablas con historial de datos
  - Botones para descargar datos en CSV
  - Componentes interactivos de `shadcn/ui`:
    - Modales
    - Tarjetas
    - Botones
    - Dropdowns

### 📎 Pie de página

- Créditos y referencias institucionales

---

## 📥 Descarga de datos

Los usuarios pueden descargar los datos históricos de:

- **Sistema meteorológico**: temperatura, humedad, presión, radiación solar, etc.
- **Sistema de energía eléctrica**: voltaje, corriente, potencia, energía acumulada

### 📁 Formatos disponibles

- **CSV**: para análisis en Excel, Google Sheets o software estadístico

### 🧪 Ejemplo de uso en la interfaz

1. Seleccionar rango de fechas
2. Presionar botón **Descargar CSV** y seleecioinas la fecha de interés
3. El archivo se descarga automáticamente con los datos filtrados

---

## 🏗️ Estado del desarrollo

- ✅ Estructura base del proyecto
- ✅ Integración con Firebase
- ✅ Dashboard interactivo con gráficos y tablas
- ✅ Funcionalidad de descarga de datos
- ✅ Uso de componentes de `shadcn/ui` para interfaz profesional
- ✅ Integración completa con todos los nodos de sensores

---

**WeatherEnergyNode** — Proyecto de monitoreo inteligente de variables ambientales y energéticas con interfaz web profesional y descarga de datos.

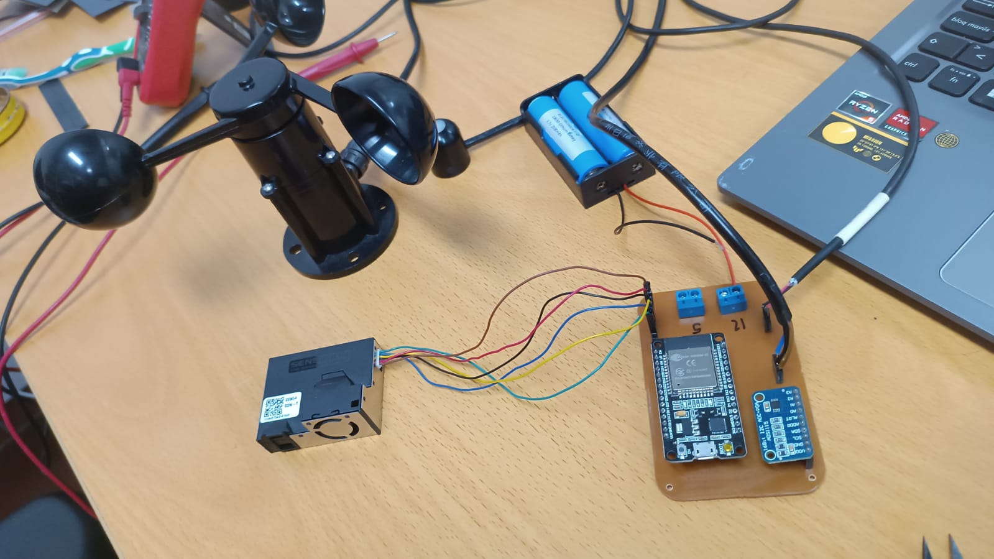
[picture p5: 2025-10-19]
docs/Meteorología/dos.jpg

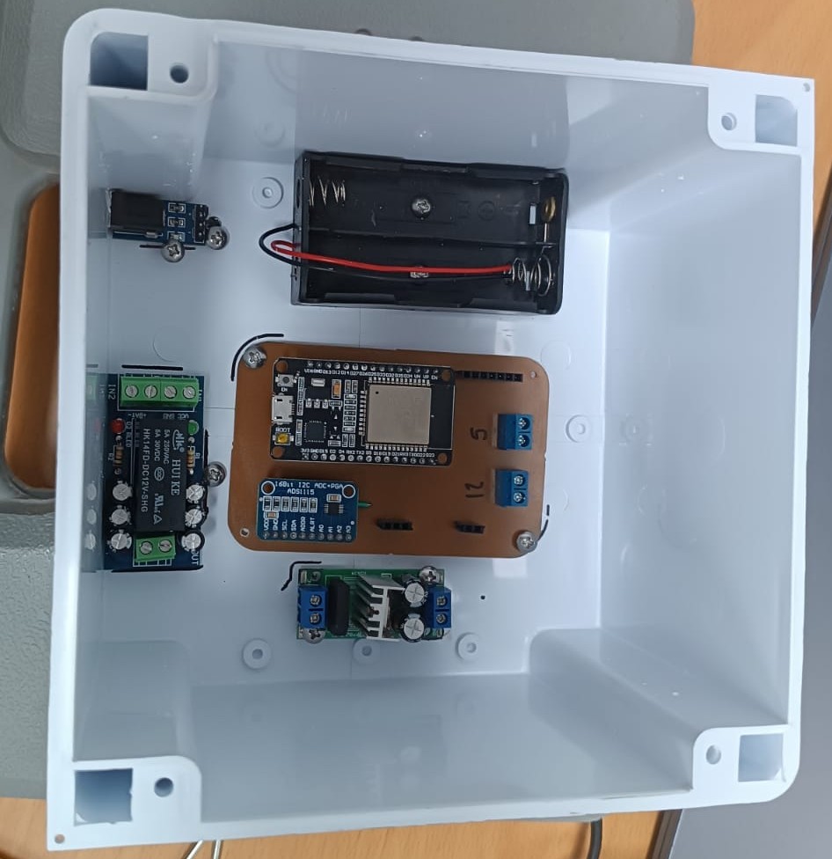
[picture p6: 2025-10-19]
docs/Meteorología/cuatro.jpg

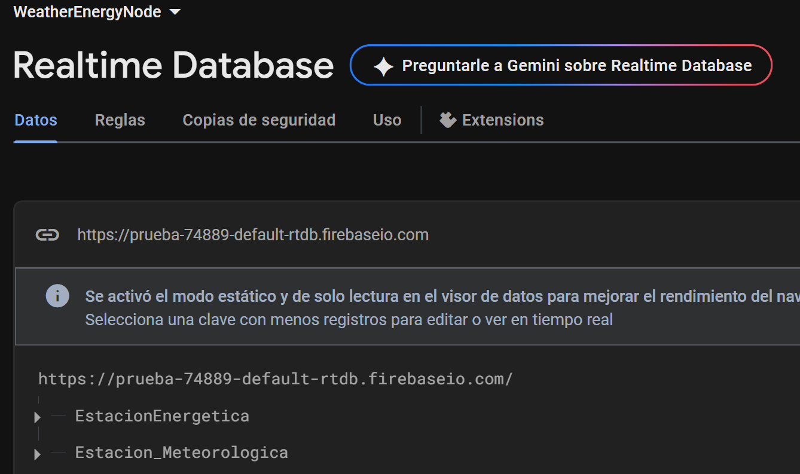
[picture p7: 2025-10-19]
docs/Página/base.png

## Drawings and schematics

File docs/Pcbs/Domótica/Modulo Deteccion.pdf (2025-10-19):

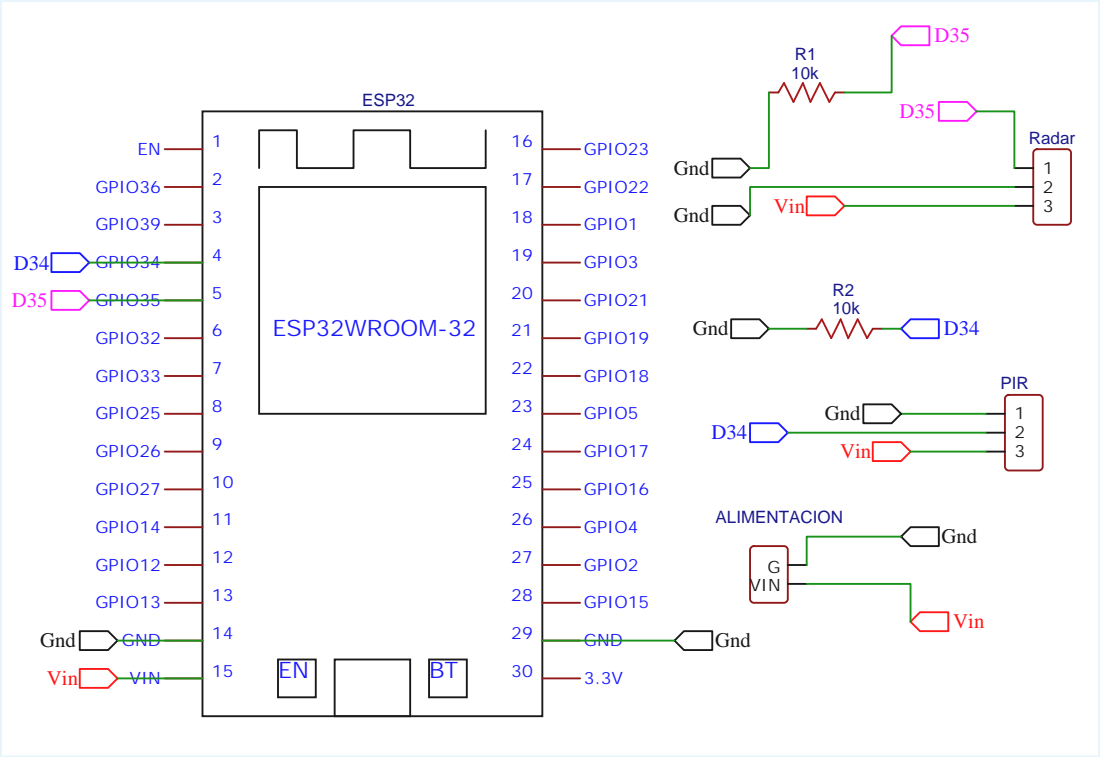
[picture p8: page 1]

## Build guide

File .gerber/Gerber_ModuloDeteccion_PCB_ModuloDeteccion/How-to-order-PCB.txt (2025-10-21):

How to Order PCB

Please refer to:
https://docs.easyeda.com/en/PCB/Order-PCB

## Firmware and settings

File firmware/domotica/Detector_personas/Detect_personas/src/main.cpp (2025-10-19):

#include <Arduino.h>
#include <BLEDevice.h>
#include <BLEUtils.h>
#include <BLEScan.h>
#include <BLEAdvertisedDevice.h>
#include <BLEClient.h>
#include <BLEAddress.h>

// UUIDs y nombre del receptor BLE
#define SERVICE_UUID        "12345678-1234-1234-1234-1234567890ab"
#define CHARACTERISTIC_UUID "12345678-1234-1234-1234-1234567890ab"
#define TARGET_NAME         "ESP32-BLE-Receptor"

#define SENSOR_1_PIN 34  // Infrarrojo
#define SENSOR_2_PIN 35  // RADAR digital


#define MUESTRAS 10
#define INTERVALO_MUESTRA 2000 // 2 segundos
#define INTERVALO_VERIFICACION 500 // ms entre verificaciones de sensor 1

bool estadoAnterior = false; // Guarda el estado anterior

// Variables globales para BLE
BLEAdvertisedDevice* myDevice = nullptr;
BLEClient* pClient = nullptr;
BLERemoteCharacteristic* pRemoteCharacteristic = nullptr;
bool connected = false;

// Clase para manejar los dispositivos anunciados durante el escaneo
class MyAdvertisedDeviceCallbacks : public BLEAdvertisedDeviceCallbacks {
  void onResult(BLEAdvertisedDevice advertisedDevice) {
    if (advertisedDevice.haveName() && advertisedDevice.getName() == TARGET_NAME) {
      Serial.println("Dispositivo BLE receptor encontrado, conectando...");
      myDevice = new BLEAdvertisedDevice(advertisedDevice);
      BLEDevice::getScan()->stop();
    }
  }
};

// Función para conectar al dispositivo BLE receptor
bool conectarBLE() {
  BLEDevice::init("");
  BLEScan* pScan = BLEDevice::getScan();
  pScan->setAdvertisedDeviceCallbacks(new MyAdvertisedDeviceCallbacks());
  pScan->setActiveScan(true);
  pScan->start(5, false); // Escanea por 5 segundos

  unsigned long startTime = millis();
  while (myDevice == nullptr && millis() - startTime < 6000) {
    delay(100);
  }

  if (myDevice != nullptr) {
    pClient = BLEDevice::createClient();
    if (pClient->connect(myDevice)) {
      Serial.println("Conectado al servidor BLE");
      BLERemoteService* pRemoteService = pClient->getService(SERVICE_UUID);
      if (pRemoteService) {
        pRemoteCharacteristic = pRemoteService->getCharacteristic(CHARACTERISTIC_UUID);
        if (pRemoteCharacteristic) {
          connected = true;
          return true;
        }
      }
      Serial.println("No se pudo obtener el servicio o la característica BLE");
      pClient->disconnect();
    } else {
      Serial.println("No se pudo conectar al servidor BLE");
    }
  } else {
    Serial.println("No se encontró el dispositivo BLE receptor");
  }
  connected = false;
  return false;
}

// Función para enviar datos por BLE
void enviarPorBLE(const char* valor) {
  if (!connected) {
    Serial.println("Intentando reconectar BLE...");
    if (!conectarBLE()) {
      Serial.println("No se pudo establecer conexión BLE para enviar datos.");
      return;
    }
  }
  if (pRemoteCharacteristic) {
    pRemoteCharacteristic->writeValue(valor);
    Serial.print("Valor enviado por BLE: ");
    Serial.println(valor);
  } else {
    Serial.println("Característica BLE no disponible.");
  }
}

// Inicialización del sistema
void setup() {
  Serial.begin(115200);

  pinMode(SENSOR_1_PIN, INPUT_PULLUP);
  pinMode(SENSOR_2_PIN, INPUT_PULLUP);

  Serial.println("Sistema iniciado. Intentando conectar BLE...");
  conectarBLE();
  Serial.println("Esperando activación del sensor infrarrojo...");
}

void loop() {
  // Espera a que el sensor 1 (PIR) se active en alto
  if (digitalRead(SENSOR_1_PIN) == HIGH) {
    Serial.println("Sensor 1 (PIR) activado.");
    for (int j = 0; j < 15; j++)
    {
      delay(1000);
      Serial.print(j);
    }
    
     Serial.println("Iniciando verificación RADAR...");
    int muestrasAltas = 0;
    for (int i = 0; i < MUESTRAS; i++) {
      int pir = digitalRead(SENSOR_2_PIN);
      Serial.print("Muestra ");
      Serial.print(i);
      Serial.print(": ");
      Serial.println(pir == HIGH ? "Presencia detectada" : "Sin presencia");
      if (pir == HIGH) { // Sensor RADAR detecta presencia (activo en alto)
        muestrasAltas++;
      }
      delay(INTERVALO_MUESTRA);
    }

    bool presenciaDetectada = (muestrasAltas >= 6);

    if (presenciaDetectada != estadoAnterior) {
      if (presenciaDetectada) {
        Serial.println("Presencia detectada, enviando 1 por BLE");
        enviarPorBLE("1");
      } else {
        Serial.println("Sin presencia, enviando 0 por BLE");
        enviarPorBLE("0");

      }
      estadoAnterior = presenciaDetectada;
    } else {
      Serial.println("Estado sin cambios, no se envía nada");
      Serial.println("Estado actual: " + String(presenciaDetectada ? "Presencia" : "Sin presencia"));
    }

    // Espera a que el sensor 1 se desactive antes de permitir una nueva verificación
    while (digitalRead(SENSOR_1_PIN) == HIGH) {
      delay(1000);
    }
    Serial.println("Esperando nueva activación del sensor PIR...");
  }

  // Si la conexión BLE se pierde, intenta reconectar
  if (connected && pClient && !pClient->isConnected()) {
    Serial.println("Conexión BLE perdida. Intentando reconectar...");
    connected = false;
    myDevice = nullptr;
    conectarBLE();
  }

  delay(INTERVALO_VERIFICACION); // Pequeño retardo para evitar lecturas continuas
}

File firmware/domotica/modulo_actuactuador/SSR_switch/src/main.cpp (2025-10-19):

#include <Arduino.h>
#include <BLEDevice.h>
#include <BLEServer.h>
#include <BLEUtils.h>
#include <BLE2902.h>

#define SERVICE_UUID        "12345678-1234-1234-1234-1234567890ab"
#define CHARACTERISTIC_UUID "12345678-1234-1234-1234-1234567890ab"

const int ssrPin = 5; // Pin para el SSR
const int manualPin = 34; // Pin para el switch manual

bool modoManual = false;
bool lastManualState = LOW;

// Variables globales para BLE
BLEServer *pServer = nullptr;
BLECharacteristic *pCharacteristic = nullptr;

// Callback para conexión y desconexión
class MyServerCallbacks : public BLEServerCallbacks {
  void onConnect(BLEServer* pServer) {
    Serial.println("Conectado por BLE");
  }

  void onDisconnect(BLEServer* pServer) {
    Serial.println("Desconectado. Reiniciando...");
    delay(500);
    pServer->startAdvertising();
  }
};

// Callback para escritura BLE
class MyCallbacks : public BLECharacteristicCallbacks {
  void onWrite(BLECharacteristic *pCharacteristic) {
    if (modoManual) {
      Serial.println("Modo manual activo: ignorando comandos BLE");
      return;
    }

    std::string value = pCharacteristic->getValue();
    if (value.length() > 0) {
      char c = value[0];
      Serial.print("Recibido por BLE: ");
      Serial.println(c);

      if (c == '1') {
        digitalWrite(ssrPin, HIGH);
        Serial.println("SSR encendido (BLE).");
      } else if (c == '0') {
        digitalWrite(ssrPin, LOW);
        Serial.println("SSR apagado (BLE).");
      } else {
        Serial.println("Valor no reconocido (esperado '0' o '1')");
      }
      delay(3000);
    }
  }
};

// Inicialización del sistema
void setup() {
  Serial.begin(115200);
  Serial.println("Iniciando BLE y configurando SSR...");

  pinMode(ssrPin, OUTPUT);// Configura el pin del SSR
  digitalWrite(ssrPin, LOW);// Asegura que el SSR esté apagado inicialmente

  pinMode(manualPin, INPUT); // Configura el pin del switch manual
  // Configura BLE
  BLEDevice::init("ESP32-BLE-Receptor");
  pServer = BLEDevice::createServer();
  pServer->setCallbacks(new MyServerCallbacks());

  BLEService *pService = pServer->createService(SERVICE_UUID);

  pCharacteristic = pService->createCharacteristic(
    CHARACTERISTIC_UUID,
    BLECharacteristic::PROPERTY_READ |
    BLECharacteristic::PROPERTY_WRITE |
    BLECharacteristic::PROPERTY_NOTIFY
  );

  pCharacteristic->addDescriptor(new BLE2902());
  pCharacteristic->setCallbacks(new MyCallbacks());

  pService->start();
  pServer->getAdvertising()->start();
  Serial.println("Esperando conexión BLE...");
}

void loop() {
  bool manualState = digitalRead(manualPin);// Lee el estado del switch manual

  // Detectar cambio de estado del pin 18
  if (manualState != lastManualState) {
    lastManualState = manualState;

    if (manualState == HIGH) {
      modoManual = true;
      digitalWrite(ssrPin, HIGH);  // Forzar encendido del SSR
      Serial.println("Modo MANUAL activado: SSR encendido");
    } else {
      modoManual = false;
      digitalWrite(ssrPin, LOW);   // Apaga el SSR al volver a modo BLE
      Serial.println("Modo MANUAL desactivado: vuelve control BLE");
    }
  }

  delay(50); // Pequeño delay para evitar rebotes y sobrecarga
}

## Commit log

2025-10-07 Segundo Commit: modificación del readme para los autores
2025-10-19 Imágenes de evidencia del proceso de desarrollo
2025-10-19 Aplicación de subida de datos meterológicos
2025-10-19 archivos medidor de energia
